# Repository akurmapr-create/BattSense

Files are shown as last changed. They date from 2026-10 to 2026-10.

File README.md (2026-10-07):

# BattSense

**ESP32 Li-ion battery monitor with voltage-based state-of-charge estimation, a custom KiCad PCB, OLED interface, and unit-tested firmware.**

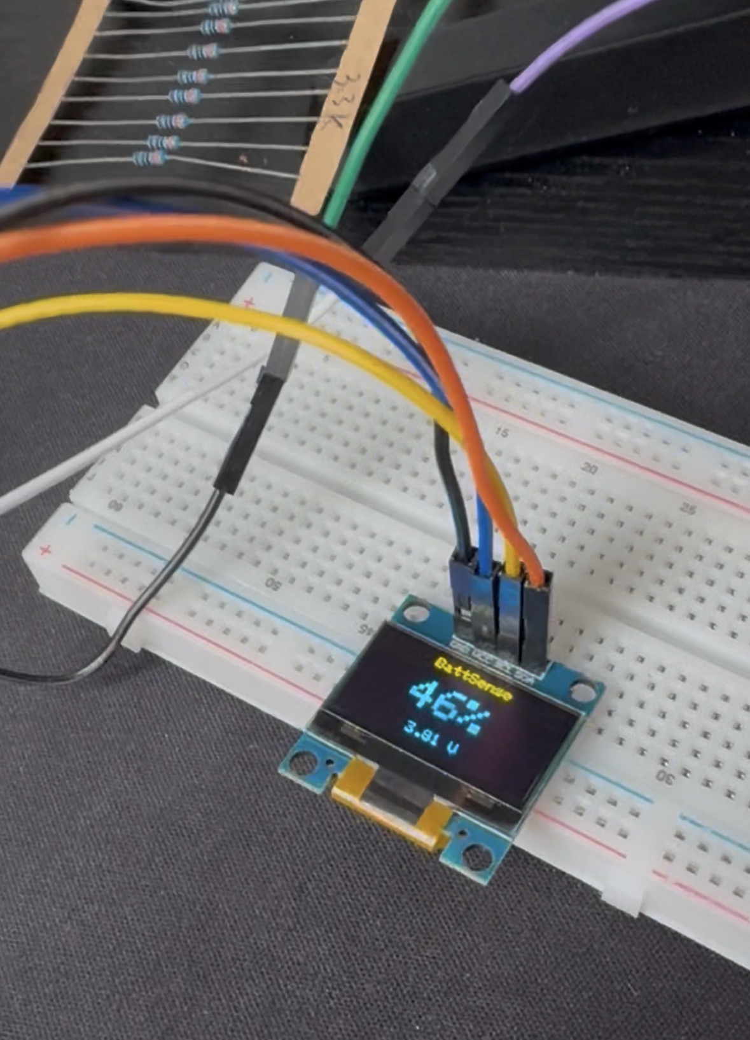
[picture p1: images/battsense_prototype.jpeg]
BattSense working prototype


BattSense is an embedded battery-monitoring system for a single-cell Li-ion battery. It measures battery voltage through a resistive analog front end, estimates battery state of charge (SoC), and displays the result locally on an OLED.

The project was developed from circuit design and breadboard validation through modular firmware, automated testing, PCB design, and enclosure development.

## Features

- Single-cell Li-ion battery voltage measurement
- ESP32 ADC acquisition on GPIO34
- Custom resistive analog front end
- ADC sample averaging
- Voltage-based state-of-charge estimation
- OCV-SoC lookup table with piecewise-linear interpolation
- 128×64 I2C OLED interface
- Modular C++ firmware
- Native unit testing with PlatformIO and Unity
- GitHub Actions continuous integration
- Custom 2-layer KiCad PCB
- Removable ESP32 DevKit architecture
- Through-hole design for hand assembly

## System Architecture

```text
          18650 Li-ion Cell
                  |
                  v
        Analog Voltage Divider
          20.1 kΩ / 13.3 kΩ
                  |
                  v
             GPIO34 ADC
                  |
                  v
           BatteryMonitor
                  |
           Battery Voltage
                  |
                  v
      StateOfChargeEstimator
                  |
           Estimated SoC
                  |
                  v
           DisplayManager
                  |
                  v
          128×64 I2C OLED
```

The firmware separates measurement, battery modeling, and presentation into independent modules.

## Hardware

### Analog Front End

The ESP32 measures the battery through a passive resistive divider.

Rev A uses:

```text
R_UPPER = 20.1 kΩ
R_LOWER = 13.3 kΩ
```

At a maximum single-cell Li-ion voltage of 4.2 V:

\[
V_{ADC}
=
4.2
\left(
\frac{13.3}
{20.1+13.3}
\right)
\approx
1.67V
\]

The divider presents a Thevenin resistance of approximately:

\[
R_{TH}
=
20.1k\Omega \parallel 13.3k\Omega
\approx
8.0k\Omega
\]

to the ESP32 ADC.

### Schematic

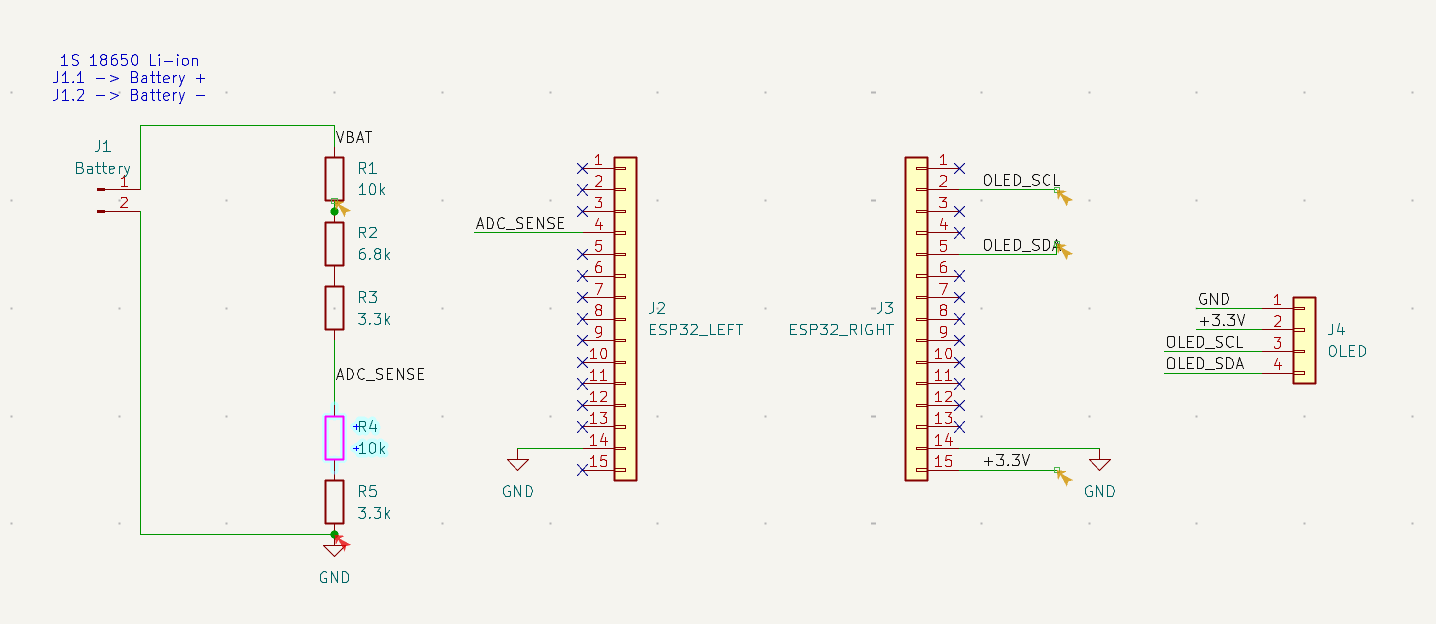
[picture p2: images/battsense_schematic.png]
BattSense schematic


The KiCad design includes:

- Battery input
- Voltage-divider analog front end
- Removable 30-pin ESP32 DevKit interface
- OLED I2C interface
- Power and ground connections

Additional analog-front-end documentation is available in [`docs/analog_front_end.md`](docs/analog_front_end.md).

## PCB Design

BattSense Rev A includes a custom **60 mm × 50 mm, 2-layer carrier PCB** designed in KiCad.

### PCB Layout

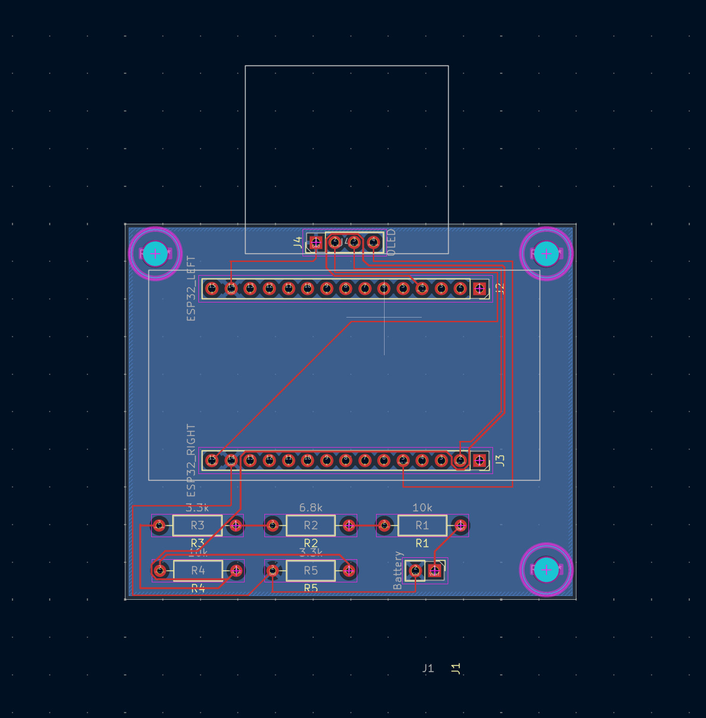
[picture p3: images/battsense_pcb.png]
BattSense PCB layout


### 3D Render

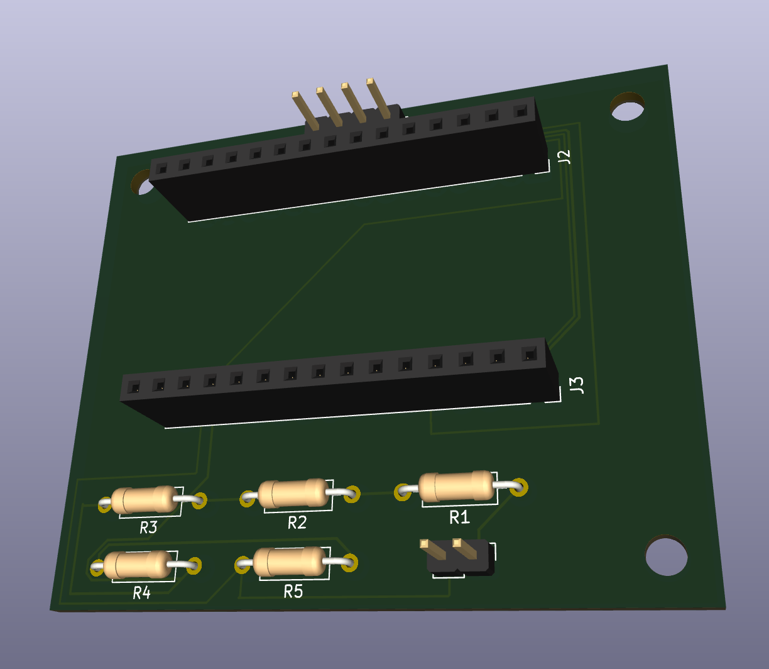
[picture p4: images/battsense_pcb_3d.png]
BattSense PCB 3D render


The PCB includes:

- Two 1×15 female sockets for a removable ESP32 DevKit
- Through-hole analog-front-end components
- OLED interface
- Battery interface
- B.Cu ground plane
- Three M3 enclosure mounting holes
- ESP32 orientation for left-side USB access

The completed layout passes KiCad design-rule checking with:

```text
Unrouted connections: 0
DRC violations:       0
```

Gerber and drill files have also been generated for Rev A fabrication.

## Firmware Architecture

The firmware is separated into dedicated modules:

```text
BatteryMonitor
      |
      | battery voltage
      v
StateOfChargeEstimator
      |
      | estimated SoC
      v
DisplayManager
      |
      v
OLED
```

### BatteryMonitor

Responsible for:

- ESP32 ADC configuration
- ADC acquisition
- Sample averaging
- ADC-voltage conversion
- Voltage-divider compensation
- Battery-voltage reporting

### StateOfChargeEstimator

Converts measured battery voltage into an estimated state of charge.

### DisplayManager

Presents battery voltage and estimated SoC on the OLED.

## State-of-Charge Estimation

BattSense Rev A uses a **voltage-based state-of-charge estimator**.

A Li-ion open-circuit-voltage versus state-of-charge lookup table is stored in firmware. When the measured voltage falls between two table entries, BattSense performs piecewise-linear interpolation.

For neighboring lookup points:

\[
(V_1,SOC_1)
\]

and

\[
(V_2,SOC_2)
\]

the interpolation factor is:

\[
t =
\frac{V-V_1}
{V_2-V_1}
\]

and the estimated state of charge is:

\[
SOC =
SOC_1 +
t(SOC_2-SOC_1)
\]

Values outside the lookup-table range are clamped to 0% or 100%.

The estimator is independent of ESP32 hardware, allowing it to be tested natively on a development machine.

> **Note:** Voltage-based SoC is an estimate rather than precision fuel gauging. Terminal voltage is affected by cell chemistry, temperature, aging, load current, and relaxation state.

See [`docs/state_of_charge.md`](docs/state_of_charge.md) for additional information about the model and its limitations.

## Testing

The SoC estimator is tested using Unity through PlatformIO's native environment.

Current tests cover:

- Lower-voltage clamping
- Upper-voltage clamping
- Exact lookup-table points
- 100% boundary behavior
- Piecewise-linear interpolation

Current result:

```text
5 test cases
5 succeeded
0 failed
```

Run the tests locally with:

```bash
cd firmware
pio test -e native
```

## Building the Firmware

BattSense uses PlatformIO with the Arduino ESP32 framework.

Clone the repository:

```bash
git clone https://github.com/akurmapr-create/BattSense.git
cd BattSense/firmware
```

Build the ESP32 firmware:

```bash
pio run -e esp32dev
```

Upload to a connected ESP32:

```bash
pio run -e esp32dev --target upload
```

Open the serial monitor:

```bash
pio device monitor
```

## Continuous Integration

BattSense uses GitHub Actions to automatically build and test the firmware on pushes and pull requests.



## Development Process

BattSense has been developed iteratively using physical hardware rather than only simulation.

```text
Requirements
    |
    v
Circuit Design
    |
    v
Breadboard Prototype
    |
    v
Measurement
    |
    v
Failure Identification
    |
    v
Design Revision
    |
    v
Validation
```

The analog front end, ADC acquisition, state-of-charge estimation, OLED interface, and PCB were developed and validated incrementally.

## Repository Structure

```text
BattSense/
|
├── .github/
│   └── workflows/
│       └── firmware.yml
|
├── docs/
│   ├── analog_front_end.md
│   ├── calculations.md
│   └── state_of_charge.md
|
├── firmware/
│   ├── include/
│   ├── src/
│   ├── test/
│   └── platformio.ini
|
├── hardware/
│   └── schematics/
│       └── BattSense_AFE/
|
├── images/
│   ├── battsense_prototype.jpeg
│   ├── battsense_schematic.png
│   ├── battsense_pcb.png
│   └── battsense_pcb_3d.png
|
└── README.md
```

## Rev A Status

- [x] Battery-voltage analog front end
- [x] Breadboard validation
- [x] ESP32 ADC integration
- [x] ADC averaging
- [x] State-of-charge estimator
- [x] SoC unit tests
- [x] OLED integration
- [x] GitHub Actions CI
- [x] KiCad schematic
- [x] Custom 2-layer PCB
- [x] ERC / DRC validation
- [x] Gerber generation
- [ ] Permanent perfboard assembly
- [ ] SolidWorks enclosure
- [ ] Final voltage validation with reference multimeter

## Roadmap

### Rev A

Complete the physical prototype:

- Assemble the permanent perfboard implementation
- Design and 3D-print the SolidWorks enclosure
- Mount the OLED and battery holder
- Complete final electrical validation

### Future Revisions

Potential improvements include:

- Cell-specific OCV-SoC characterization
- Current sensing
- Coulomb counting
- Temperature compensation
- Load-compensated SoC estimation
- Dedicated fuel-gauge evaluation
- Custom integrated ESP32 PCB

## Tools

- ESP32
- C++ / Arduino
- PlatformIO
- Unity
- GitHub Actions
- KiCad
- SolidWorks
- Git / GitHub

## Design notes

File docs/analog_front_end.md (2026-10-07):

# Analog Front-End Design

## Overview

The BattSense analog front-end measures the terminal voltage of a single-cell (1S) 18650 lithium-ion battery using the ESP32 ADC.

Because the maximum battery voltage exceeds the selected ADC measurement range, a passive resistive voltage divider scales the battery voltage before it reaches the ESP32.

> **Note**
>
> BattSense is a battery telemetry platform, **not** a Battery Management System (BMS). The analog front-end performs voltage measurement only. It does not provide charging control, cell balancing, over-current protection, or battery disconnect functionality.

---

## Requirements

| Requirement | Value |
| :--- | ---: |
| Battery chemistry | 1S Li-ion (18650) |
| Maximum battery voltage | 4.2 V |
| Microcontroller | ESP32-WROOM-32 DevKit |
| ADC peripheral | ADC1 |
| ADC input | GPIO34 |
| ADC resolution | 12 bit |
| ADC attenuation | 6 dB |
| Revised maximum ADC target | ~1.6 V |
| Target ADC source impedance | ~8 kΩ |

---

## System Architecture

```text
18650 Battery
      │
      ▼
Voltage Divider
      │
      ▼
ADC_SENSE
      │
      ▼
GPIO34 / ADC1
      │
      ▼
BatteryMonitor
      │
      ▼
Battery Voltage
      │
      ▼
Future Telemetry System
```

The ESP32 development board is powered independently through USB during Rev A testing. The 18650 cell is used as the measured source and does not power the ESP32.

The battery and ESP32 share a common ground so that the ADC measurement has the correct voltage reference.

---

## ADC Configuration

BattSense uses:

- ADC1
- GPIO34
- 12-bit ADC resolution
- 6 dB attenuation

ADC1 was selected to provide a dedicated analog measurement path and avoid the resource-sharing limitations associated with ADC2 when ESP32 wireless functionality is used.

The 6 dB attenuation setting was retained after prototype testing, but the analog front-end scaling was revised to keep the ADC input comfortably within the recommended measurement range.

---

# Analog Front-End Revision History

## Initial Design

The original analog front-end targeted:

\[
V_{BAT,MAX}=4.2V
\]

and:

\[
V_{ADC,MAX}=2.0V
\]

The resulting divider used nominal equivalent resistances of:

\[
R_{UPPER}=16.8k\Omega
\]

\[
R_{LOWER}=15.1k\Omega
\]

This produced a theoretical maximum ADC voltage of approximately:

\[
V_{ADC,MAX}\approx1.99V
\]

The design also maintained a source impedance of approximately 8 kΩ and a divider current of approximately 132 µA.

### Prototype Result

During breadboard testing, the ADC input was approximately 1.9 V and repeated calls to `analogRead()` returned:

```text
4095
4095
4095
...
```

A value of 4095 represents the maximum possible output of a 12-bit ADC and indicated that the ADC was saturating.

This demonstrated that the original 2.0 V target was too aggressive for reliable operation with the ESP32 ADC configured for 6 dB attenuation.

Rather than compensating for the behavior in firmware, the analog front-end was redesigned.

---

# Revised Analog Front-End

## Revised ADC Target

The maximum ADC target was reduced from approximately:

\[
2.0V
\]

to:

\[
\boxed{1.6V}
\]

at the maximum expected battery voltage of:

\[
4.2V
\]

This provides additional headroom below the upper portion of the usable ADC measurement range.

---

## Final Prototype Divider

The revised breadboard prototype uses equivalent resistances of:

\[
\boxed{R_{UPPER}=20.7k\Omega}
\]

and:

\[
\boxed{R_{LOWER}=13.0k\Omega}
\]

The divider topology is:

```text
VBAT
 │
 │
20.7 kΩ
 │
 ├──────── ADC_SENSE ─────── GPIO34
 │
13.0 kΩ
 │
GND
```

If an equivalent resistance is constructed from multiple physical resistors, the KiCad schematic documents the individual physical components used in the prototype.

---

## Revised Maximum ADC Voltage

The divider relationship is:

\[
V_{ADC}
=
V_{BAT}
\left(
\frac{R_{LOWER}}
{R_{UPPER}+R_{LOWER}}
\right)
\]

At the maximum battery voltage:

\[
V_{ADC}
=
4.2
\left(
\frac{13.0}
{20.7+13.0}
\right)
\]

Therefore:

\[
\boxed{V_{ADC,MAX}\approx1.62V}
\]

This is significantly lower than the original approximately 2.0 V target and prevents the ADC from operating near the saturation condition observed during initial testing.

---

## Source Impedance

The source impedance presented to the ADC is approximately the Thevenin equivalent resistance of the divider:

\[
R_{SOURCE}
=
R_{UPPER}\parallel R_{LOWER}
\]

For the revised divider:

\[
R_{SOURCE}
=
20.7k\Omega\parallel13.0k\Omega
\]

which gives:

\[
\boxed{R_{SOURCE}\approx7.99k\Omega}
\]

This remains extremely close to the original design target of approximately 8 kΩ.

---

## Divider Current

At the maximum battery voltage:

\[
R_{TOTAL}
=
20.7k\Omega+13.0k\Omega
=
33.7k\Omega
\]

The divider current is therefore:

\[
I_{DIVIDER}
=
\frac{4.2V}{33.7k\Omega}
\]

\[
\boxed{I_{DIVIDER}\approx125\mu A}
\]

The revised design therefore slightly reduces continuous divider current compared with the original prototype.

---

# Prototype Validation

## Initial Prototype

The initial divider produced an ADC input near approximately 1.9 V during testing.

The ESP32 repeatedly returned a raw ADC value of:

```text
4095
```

indicating ADC saturation.

---

## Revised Prototype

After changing the divider to approximately:

- 20.7 kΩ upper resistance
- 13.0 kΩ lower resistance

the raw ADC measurements were approximately:

```text
3109
3111
3103
3107
3113
3110
3114
3098
3093
3099
3145
3088
3098
3149
3119
3120
3107
3152
```

The ADC was therefore no longer saturated.

This experimentally verified that the revised analog-front-end scaling moved the ADC input back into a usable measurement region.

The variation between individual ADC samples will be characterized separately before deciding whether averaging or digital filtering is necessary.

---
## ADC Sample Averaging

After resolving the ADC saturation issue, repeated battery-voltage measurements were collected to characterize measurement variation.

With individual calibrated ADC measurements, the observed battery-voltage output ranged approximately from:

\[
3.808V \text{ to } 3.847V
\]

giving a peak-to-peak variation of:

\[
\Delta V_{PP}=39mV
\]

Because battery terminal voltage changes relatively slowly, multi-sample averaging was evaluated as a method of reducing random ADC variation.

BattSense was configured to average 16 calibrated ADC measurements for each reported voltage measurement.

After implementing 16-sample averaging, the observed battery-voltage range was approximately:

\[
3.818V \text{ to } 3.836V
\]

giving:

\[
\Delta V_{PP}=18mV
\]

The observed peak-to-peak variation was therefore reduced by approximately:

\[
\frac{39-18}{39}\times100\approx54\%
\]

Based on this experimental result, 16-sample averaging was retained in the Rev A BatteryMonitor implementation.

The raw ADC diagnostic remains a single conversion and therefore exhibits greater sample-to-sample variation than the averaged production voltage measurement.

# Firmware Interface

The analog front-end is represented in firmware by the `BatteryMonitor` module.

The module:

- Configures GPIO34 as the battery ADC input.
- Configures 12-bit ADC resolution.
- Configures 6 dB attenuation.
- Acquires raw ADC measurements for diagnostics.
- Obtains ADC-pin voltage measurements.
- Applies voltage-divider compensation.
- Returns the estimated battery terminal voltage.

The firmware uses the actual analog-front-end resistor values rather than a hard-coded divider multiplier.

Conceptually:

\[
V_{BAT}
=
V_{ADC}
\left(
\frac{R_{UPPER}+R_{LOWER}}
{R_{LOWER}}
\right)
\]

This keeps the firmware implementation directly traceable to the hardware design.

---

# Design Tradeoffs

| Decision | Benefit | Tradeoff |
| :--- | :--- | :--- |
| ADC1 / GPIO34 | Suitable dedicated analog input | Consumes one ADC1 channel |
| 6 dB attenuation | Retains selected ADC configuration | Requires external voltage scaling |
| ~1.6 V maximum target | Prevents observed saturation and adds headroom | Uses less of the theoretical ADC range |
| ~8 kΩ source impedance | Supports reliable ADC sampling | Requires relatively low divider resistance |
| Passive divider | Simple and inexpensive | Continuously draws battery current |
| ~125 µA divider current | Acceptable for Rev A | Too high for future ultra-low-power designs |

---

# Future Improvements

Potential future improvements include:

- Characterizing ADC measurement error across multiple battery voltages.
- Quantifying sample-to-sample ADC noise.
- Determining whether sample averaging improves measurement repeatability.
- Characterizing divider tolerance using higher-accuracy test equipment.
- Adding a switched divider for lower sleep current.
- Evaluating an ADC input capacitor if higher divider resistance is used.
- Designing a dedicated BattSense PCB after breadboard validation is complete.

Filtering and averaging will only be introduced after measurement data demonstrates a need for them.

---

# Lessons Learned

The Rev A voltage-measurement subsystem demonstrated the importance of validating analog designs against real hardware rather than relying exclusively on theoretical calculations.

Key findings included:

1. The original approximately 2.0 V ADC target caused the 12-bit ESP32 ADC reading to saturate at 4095 when using 6 dB attenuation.

2. The analog front end was redesigned for approximately 1.6 V maximum ADC input at a 4.2 V battery voltage.

3. The revised 20.7 kΩ / 13.0 kΩ divider eliminated the observed ADC saturation while maintaining approximately 8 kΩ source impedance.

4. Separating raw ADC count, ADC-pin voltage, and reconstructed battery voltage significantly simplified troubleshooting.

5. Measurements were used to justify signal-processing changes rather than adding filtering preemptively.

6. Sixteen-sample averaging reduced observed battery-voltage peak-to-peak variation from approximately 39 mV to 18 mV.

7. The available multimeter was sufficient for functional validation but was not accurate enough to characterize absolute measurement accuracy. Therefore, BattSense Rev A claims functional and repeatable battery telemetry rather than precision voltage measurement.

# References

- ESP32-WROOM-32 Datasheet
- ESP32 Technical Reference Manual
- ESP-IDF ADC Documentation
- Arduino-ESP32 ADC API Documentation

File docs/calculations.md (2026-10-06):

# Analog Front-End Calculations

This document contains the calculations used to design and revise the BattSense battery-voltage analog front end.

The original design calculations are retained to document the engineering process that led to the revised prototype.

---

# 1. System Requirements

Maximum battery voltage:

\[
V_{BAT,MAX}=4.2V
\]

ADC:

```text
ESP32 ADC1
GPIO34
12-bit resolution
6 dB attenuation
```

Target ADC source impedance:

\[
R_{SOURCE}\approx8k\Omega
\]

---

# 2. Original Analog Front-End

## Original ADC Target

The initial design targeted:

\[
V_{ADC,MAX}=2.0V
\]

at:

\[
V_{BAT,MAX}=4.2V
\]

---

## Original Divider Ratio

The voltage-divider equation is:

\[
V_{OUT}
=
V_{IN}
\left(
\frac{R_{LOWER}}
{R_{UPPER}+R_{LOWER}}
\right)
\]

Substituting the original requirements:

\[
2.0
=
4.2
\left(
\frac{R_{LOWER}}
{R_{UPPER}+R_{LOWER}}
\right)
\]

Therefore:

\[
\frac{R_{LOWER}}
{R_{UPPER}+R_{LOWER}}
=
\frac{2.0}{4.2}
\]

\[
=
\frac{10}{21}
\]

Solving:

\[
10(R_{UPPER}+R_{LOWER})
=
21R_{LOWER}
\]

\[
10R_{UPPER}+10R_{LOWER}
=
21R_{LOWER}
\]

\[
10R_{UPPER}
=
11R_{LOWER}
\]

Therefore:

\[
\boxed{
R_{UPPER}:R_{LOWER}=11:10
}
\]

---

## Original Prototype Values

The initial prototype used nominal equivalent resistances of:

\[
R_{UPPER}=16.8k\Omega
\]

\[
R_{LOWER}=15.1k\Omega
\]

The actual physical prototype used series combinations to approximate these equivalent resistances.

---

## Original Maximum ADC Voltage

\[
V_{ADC}
=
4.2
\left(
\frac{15.1}
{16.8+15.1}
\right)
\]

\[
V_{ADC}
=
4.2
\left(
\frac{15.1}
{31.9}
\right)
\]

\[
\boxed{
V_{ADC}\approx1.99V
}
\]

---

## Original Source Impedance

\[
R_{SOURCE}
=
R_{UPPER}\parallel R_{LOWER}
\]

\[
R_{SOURCE}
=
\frac{(16.8k)(15.1k)}
{16.8k+15.1k}
\]

\[
\boxed{
R_{SOURCE}\approx7.95k\Omega
}
\]

---

## Original Divider Current

\[
R_{TOTAL}
=
16.8k+15.1k
=
31.9k\Omega
\]

\[
I
=
\frac{4.2V}{31.9k\Omega}
\]

\[
\boxed{
I\approx132\mu A
}
\]

---

# 3. Initial Prototype Test Result

During breadboard validation, the ADC input approached approximately 1.9 V.

Repeated raw ADC measurements returned:

```text
4095
4095
4095
...
```

For a 12-bit ADC:

\[
ADC_{MAX}=2^{12}-1=4095
\]

The repeated maximum value indicated ADC saturation.

The analog-front-end design was therefore revised instead of attempting to compensate for the saturation in firmware.

---

# 4. Revised Analog Front-End

## Revised ADC Target

The new design target is:

\[
\boxed{
V_{ADC,MAX}\approx1.6V
}
\]

for:

\[
V_{BAT,MAX}=4.2V
\]

The required divider ratio is therefore approximately:

\[
K
=
\frac{1.6}{4.2}
\]

\[
\boxed{
K\approx0.381
}
\]

where:

\[
K=
\frac{R_{LOWER}}
{R_{UPPER}+R_{LOWER}}
\]

---

# 5. Revised Prototype Resistor Selection

Available resistor combinations produced:

\[
\boxed{
R_{UPPER}=20.7k\Omega
}
\]

\[
\boxed{
R_{LOWER}=13.0k\Omega
}
\]

Total divider resistance:

\[
R_{TOTAL}
=
20.7k+13.0k
\]

\[
\boxed{
R_{TOTAL}=33.7k\Omega
}
\]

---

# 6. Revised Divider Ratio

\[
K
=
\frac{13.0}
{20.7+13.0}
\]

\[
K
=
\frac{13.0}{33.7}
\]

\[
\boxed{
K\approx0.3858
}
\]

---

# 7. Revised Maximum ADC Voltage

At the maximum battery voltage:

\[
V_{ADC,MAX}
=
4.2(0.3858)
\]

\[
\boxed{
V_{ADC,MAX}\approx1.62V
}
\]

This is close to the revised 1.6 V design target.

---

# 8. Revised Source Impedance

The ADC sees approximately the Thevenin equivalent resistance of the divider:

\[
R_{SOURCE}
=
R_{UPPER}\parallel R_{LOWER}
\]

\[
R_{SOURCE}
=
\frac{(20.7k)(13.0k)}
{20.7k+13.0k}
\]

\[
R_{SOURCE}
=
\frac{269.1}
{33.7}
k\Omega
\]

\[
\boxed{
R_{SOURCE}\approx7.99k\Omega
}
\]

This is almost exactly the original 8 kΩ source-impedance target.

---

# 9. Revised Divider Current

At maximum battery voltage:

\[
I_{DIVIDER}
=
\frac{V_{BAT}}
{R_{TOTAL}}
\]

\[
I_{DIVIDER}
=
\frac{4.2}
{33.7k}
\]

\[
\boxed{
I_{DIVIDER}\approx125\mu A
}
\]

The revised divider therefore consumes slightly less current than the original design.

---

# 10. Battery Voltage Reconstruction

The ADC measures:

\[
V_{ADC}
=
V_{BAT}
\left(
\frac{R_{LOWER}}
{R_{UPPER}+R_{LOWER}}
\right)
\]

Solving for battery voltage:

\[
V_{BAT}
=
V_{ADC}
\left(
\frac{R_{UPPER}+R_{LOWER}}
{R_{LOWER}}
\right)
\]

Using the revised resistor values:

\[
V_{BAT}
=
V_{ADC}
\left(
\frac{20.7+13.0}
{13.0}
\right)
\]

\[
V_{BAT}
=
V_{ADC}
\left(
\frac{33.7}{13.0}
\right)
\]

Therefore:

\[
\boxed{
V_{BAT}\approx2.5923V_{ADC}
}
\]

The firmware calculates this relationship from the resistor values rather than storing `2.5923` as a hard-coded multiplier.

---

# 11. Revised Prototype ADC Test

After installing the revised divider, the following raw ADC samples were observed:

```text
3109
3111
3103
3107
3113
3110
3114
3098
3093
3099
3145
3088
3098
3149
3119
3120
3107
3152
```

Unlike the original design, the ADC was no longer pinned at:

```text
4095
```

This verifies that the revised voltage divider successfully moved the ADC input away from saturation.

The sample variation will be characterized separately before deciding whether digital averaging or filtering is necessary.

---

# 12. Design Comparison

| Parameter | Original Design | Revised Design |
| :--- | ---: | ---: |
| Maximum battery voltage | 4.2 V | 4.2 V |
| ADC target | 2.0 V | ~1.6 V |
| Upper resistance | 16.8 kΩ | 20.7 kΩ |
| Lower resistance | 15.1 kΩ | 13.0 kΩ |
| Maximum ADC voltage | ~1.99 V | ~1.62 V |
| Source impedance | ~7.95 kΩ | ~7.99 kΩ |
| Divider current @ 4.2 V | ~132 µA | ~125 µA |
| Raw ADC prototype behavior | Saturated at 4095 | ~3100 counts |

---

# 13. Engineering Conclusion

The original analog front-end met its calculated divider and source-impedance requirements but produced ADC saturation during physical testing.

The revised design:

- Reduces maximum ADC input voltage.
- Preserves approximately 8 kΩ source impedance.
- Slightly reduces continuous divider current.
- Eliminates the observed raw ADC saturation.
- Maintains sufficient range for measurement of a 1S lithium-ion battery.

This revision demonstrates the complete engineering cycle:

```text
Requirements
    ↓
Design
    ↓
Calculation
    ↓
Prototype
    ↓
Test
    ↓
Failure Observation
    ↓
Root-Cause Investigation
    ↓
Design Revision
    ↓
Verification
```

Further optimization will be based on measured ADC accuracy and noise rather than assumptions.

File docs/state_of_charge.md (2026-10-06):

# State-of-Charge Estimation

## Overview

BattSense Rev A estimates the state of charge (SoC) of a single-cell lithium-ion battery using the battery voltage measured by the `BatteryMonitor` module.

The estimator uses a tabular open-circuit-voltage (OCV) versus state-of-charge relationship and piecewise-linear interpolation between adjacent lookup-table points.

The resulting percentage is an **estimated state of charge** and should not be interpreted as a precision measurement of remaining battery capacity.

---

## System Architecture

The state-of-charge estimator is intentionally separated from the battery measurement hardware and firmware.

```text
18650 Battery
      |
      v
Analog Front End
      |
      v
BatteryMonitor
      |
      | Battery Voltage
      v
StateOfChargeEstimator
      |
      | Estimated SoC (%)
      v
DisplayManager
      |
      v
OLED Display
```

Each module has a separate responsibility:

- `BatteryMonitor` measures battery voltage.
- `StateOfChargeEstimator` converts battery voltage into an estimated SoC.
- `DisplayManager` will present the resulting information to the user.

This separation allows the battery measurement, SoC model, and user interface to evolve independently.

---

# Rev A Estimation Method

BattSense Rev A uses:

> **OCV-SoC lookup table + piecewise-linear interpolation**

A lookup-table approach was selected because the lithium-ion voltage-versus-state-of-charge relationship is nonlinear.

A simple linear relationship such as:

\[
3.0V = 0\%
\]

and:

\[
4.2V = 100\%
\]

would incorrectly assume that battery voltage changes linearly with state of charge.

Instead, BattSense stores several OCV-SoC operating points and interpolates between neighboring points.

---

# OCV-SoC Lookup Table

BattSense Rev A uses the following generic lithium-ion OCV-SoC reference model:

| OCV (V) | SoC (%) |
| ---: | ---: |
| 3.0519 | 0 |
| 3.6594 | 10 |
| 3.7167 | 20 |
| 3.7611 | 30 |
| 3.7915 | 40 |
| 3.8275 | 50 |
| 3.8772 | 60 |
| 3.9401 | 70 |
| 4.0128 | 80 |
| 4.0923 | 90 |
| 4.1797 | 100 |

The lookup-table values are based on the example tabular OCV-SoC model presented in the following review:

> M. A. Hannan et al.,  
> "Open-Circuit Voltage Models for Battery Management Systems: A Review,"  
> *Energies*, vol. 15, no. 18, 6803, 2022.

DOI:

https://doi.org/10.3390/en15186803

The referenced work discusses tabular OCV-SoC representations and interpolation-based battery models.

BattSense uses this data as a **generic Rev A approximation** rather than as a cell-specific characterization of the particular 18650 used during development.

---

# Piecewise-Linear Interpolation

When the measured battery voltage falls between two entries in the lookup table, BattSense estimates the state of charge using linear interpolation between those neighboring points.

Consider two adjacent lookup-table points:

\[
(V_1,SOC_1)
\]

and:

\[
(V_2,SOC_2)
\]

For a measured battery voltage:

\[
V
\]

where:

\[
V_1 < V < V_2
\]

the interpolation fraction is:

\[
t =
\frac{V-V_1}
{V_2-V_1}
\]

The estimated state of charge is then:

\[
SOC =
SOC_1 +
t(SOC_2-SOC_1)
\]

---

## Example

Suppose the battery voltage is:

\[
V=3.85V
\]

The surrounding lookup-table entries are:

\[
3.8275V \rightarrow 50\%
\]

and:

\[
3.8772V \rightarrow 60\%
\]

The interpolation fraction is:

\[
t=
\frac{3.85-3.8275}
{3.8772-3.8275}
\]

\[
t\approx0.453
\]

The estimated state of charge is therefore:

\[
SOC=
50+0.453(60-50)
\]

\[
SOC\approx54.5\%
\]

Therefore:

\[
\boxed{SOC\approx55\%}
\]

The OLED display may round the calculated value to the nearest whole percentage.

---

# Boundary Conditions

The estimator must always return a value between:

\[
0\%
\]

and:

\[
100\%
\]

If the measured voltage is greater than or equal to the highest lookup-table voltage:

\[
V\ge4.1797V
\]

the estimator returns:

\[
\boxed{SOC=100\%}
\]

If the measured voltage is less than or equal to the lowest lookup-table voltage:

\[
V\le3.0519V
\]

the estimator returns:

\[
\boxed{SOC=0\%}
\]

This prevents invalid outputs such as:

```text
107%
```

or:

```text
-8%
```

---

# Firmware Architecture

The estimator is implemented as a dedicated firmware module:

```text
firmware/
├── include/
│   └── StateOfChargeEstimator.h
│
└── src/
    └── StateOfChargeEstimator.cpp
```

The public interface is intentionally small.

Conceptually:

```cpp
class StateOfChargeEstimator
{
public:
    float estimate(float batteryVoltage) const;
};
```

The module receives battery voltage as its input and returns estimated state of charge.

For example:

```text
Input:
3.85 V

Output:
~54.5 %
```

---

# Separation of Model and Algorithm

The OCV-SoC lookup table represents the **battery model**.

The interpolation function represents the **estimation algorithm**.

These are intentionally separated.

```text
OCV-SOC Lookup Table
        |
        | battery model
        v
Interpolation Algorithm
        |
        v
Estimated SoC
```

This means a future BattSense revision could replace the generic lookup table with cell-specific characterization data without redesigning the interpolation algorithm.

---

# Why SoC Estimation Is Not Part of BatteryMonitor

`BatteryMonitor` is responsible for answering:

> What is the measured battery voltage?

`StateOfChargeEstimator` is responsible for answering:

> Given this voltage and our battery model, what is the estimated state of charge?

These are separate responsibilities.

Keeping them separate prevents battery-model assumptions from becoming coupled to the ADC measurement implementation.

---

# Limitations

Voltage-based state-of-charge estimation has important limitations.

## Terminal Voltage Is Not Always OCV

Open-circuit voltage is ideally measured when the battery has been allowed to rest and transient electrochemical effects have decayed.

BattSense Rev A measures battery terminal voltage.

Under load:

\[
V_{terminal}
\neq
V_{OCV}
\]

because battery internal resistance and electrochemical polarization can cause the terminal voltage to change.

Therefore, the calculated percentage should be interpreted as an approximation.

---

## Cell Chemistry

Different lithium-ion chemistries have different OCV-SoC relationships.

Examples include:

- NMC
- NCA
- LCO
- LFP

BattSense Rev A does not attempt to automatically identify battery chemistry.

The selected model is intended as a generic lithium-ion approximation for the Rev A prototype.

---

## Temperature

Battery voltage behavior changes with temperature.

BattSense Rev A does not perform temperature compensation.

Temperature-aware SoC estimation may be investigated in a future revision.

---

## Aging

As lithium-ion cells age:

- Internal resistance increases.
- Available capacity decreases.
- Voltage behavior may change.

The Rev A estimator does not compensate for battery aging.

---

## Load Current

BattSense Rev A does not measure battery current.

Therefore it cannot compensate for load-induced voltage drop or perform coulomb counting.

This limits the accuracy of voltage-only state-of-charge estimation.

---

# Why BattSense Uses Voltage-Based SoC in Rev A

The goal of Rev A is not to implement a precision fuel gauge.

The goal is to build a modular embedded telemetry platform while demonstrating:

- Analog battery-voltage measurement
- ADC configuration and calibration
- Hardware/firmware co-design
- Lookup-table modeling
- Piecewise-linear interpolation
- Modular C++ architecture
- Automated testing
- CI-based firmware development
- Embedded user-interface development

Voltage-based SoC estimation provides an appropriate balance between useful functionality and Rev A project scope.

---

# Future Improvements

Possible future improvements include:

- Cell-specific OCV-SoC characterization
- Temperature compensation
- Battery current measurement
- Coulomb counting
- Load compensation
- Battery aging compensation
- Rest-state detection
- Combining OCV estimation with coulomb counting
- Dedicated fuel-gauge IC evaluation

These improvements are intentionally outside the scope of BattSense Rev A.

---

# References

## Primary OCV Model Reference

M. A. Hannan et al.,  
"Open-Circuit Voltage Models for Battery Management Systems: A Review,"  
*Energies*, vol. 15, no. 18, 6803, 2022.

DOI:

https://doi.org/10.3390/en15186803

---

## Additional Reference

H. He, X. Zhang, R. Xiong, Y. Xu, and H. Guo,  
"Online model-based estimation of state-of-charge and open-circuit voltage of lithium-ion batteries in electric vehicles,"  
*Energy*, vol. 39, no. 1, pp. 310-318, 2012.

DOI:

https://doi.org/10.1016/j.energy.2012.01.009

This work discusses experimentally derived OCV-SoC relationships and interpolation-based SoC estimation.

---

# Rev A Definition

BattSense reports:

> **Estimated Battery State of Charge**

It does **not** claim to provide precision remaining-capacity measurement or commercial fuel-gauge accuracy.

This distinction should be maintained in firmware documentation, the OLED user interface, and the project README.

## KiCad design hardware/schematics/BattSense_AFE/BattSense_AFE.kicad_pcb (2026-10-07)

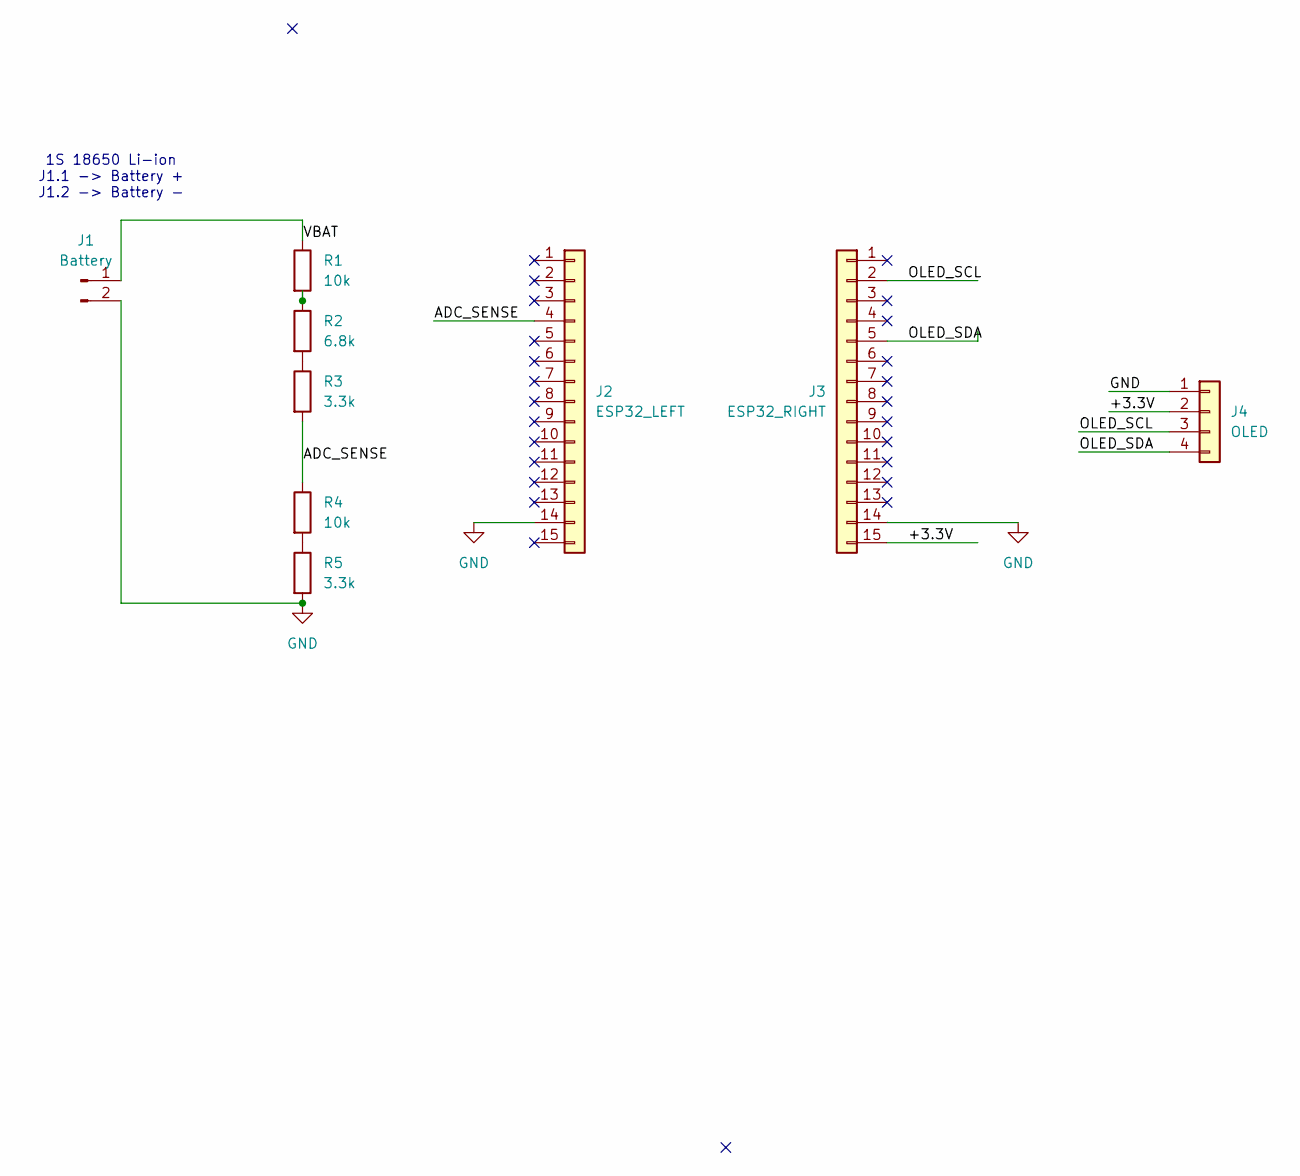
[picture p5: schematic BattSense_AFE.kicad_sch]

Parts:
J1: Battery; PinHeader_1x02_P2.54mm_Vertical
J2: ESP32_LEFT; PinSocket_1x15_P2.54mm_Vertical
J3: ESP32_RIGHT; PinSocket_1x15_P2.54mm_Vertical
J4: OLED; PinHeader_1x04_P2.54mm_Vertical
R1, R4: 10k; R_Axial_DIN0207_L6.3mm_D2.5mm_P10.16mm_Horizontal
R2: 6.8k; R_Axial_DIN0207_L6.3mm_D2.5mm_P10.16mm_Horizontal
R3, R5: 3.3k; R_Axial_DIN0207_L6.3mm_D2.5mm_P10.16mm_Horizontal

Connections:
/+3.3V: J3.15, J4.2
/ADC_SENSE: J2.4, R3.2, R4.1
/OLED_SCL: J3.2, J4.3
/OLED_SDA: J3.5, J4.4
/VBAT: J1.1, R1.1
GND: J1.2, J2.14, J3.14, J4.1, R5.2
unnamed: R1.2, R2.1
unnamed: R2.2, R3.1
unnamed: R4.2, R5.1

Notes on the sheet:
1S 18650 Li-ion J1.1 -> Battery + J1.2 -> Battery -

Board: 2 copper layers, 9 parts (0 on the bottom side), 9 nets, no tracks yet.

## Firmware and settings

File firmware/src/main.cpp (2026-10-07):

#include <Arduino.h>

#include "BatteryMonitor.h"
#include "StateOfChargeEstimator.h"
#include "DisplayManager.h"

BatteryMonitor battery;
StateOfChargeEstimator socEstimator;
DisplayManager display;

void setup()
{
    Serial.begin(115200);

    battery.begin();

    if (!display.begin())
    {
        Serial.println("OLED initialization failed.");

        while (true)
        {
            delay(1000);
        }
    }

    Serial.println("BattSense initialized.");
}

void loop()
{
    const BatteryDiagnostics diagnostics = battery.getDiagnostics();

    const float stateOfCharge =
        socEstimator.estimate(diagnostics.batteryVoltage);

    display.showBattery(
        diagnostics.batteryVoltage,
        stateOfCharge
    );

    Serial.println("----- Battery Diagnostics -----");

    Serial.print("Raw ADC:          ");
    Serial.println(diagnostics.rawAdcCount);

    Serial.print("ADC Voltage:      ");
    Serial.print(diagnostics.adcVoltage, 3);
    Serial.println(" V");

    Serial.print("Battery Voltage:  ");
    Serial.print(diagnostics.batteryVoltage, 3);
    Serial.println(" V");

    Serial.print("Estimated SoC:    ");
    Serial.print(stateOfCharge, 1);
    Serial.println(" %");

    Serial.println("-------------------------------");

    delay(1000);
}

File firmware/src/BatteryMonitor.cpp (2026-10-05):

#include "BatteryMonitor.h"

void BatteryMonitor::begin()
{
    analogReadResolution(ADC_RESOLUTION);
    analogSetPinAttenuation(ADC_PIN, ADC_6db);
}

float BatteryMonitor::getVoltage()
{
    const float adcVoltage = readADCVoltage();

    return adcToBatteryVoltage(adcVoltage);
}

BatteryDiagnostics BatteryMonitor::getDiagnostics()
{
    BatteryDiagnostics diagnostics{};

    diagnostics.rawAdcCount = readRawADC();
    diagnostics.adcVoltage = readADCVoltage();
    diagnostics.batteryVoltage =
        adcToBatteryVoltage(diagnostics.adcVoltage);

    return diagnostics;
}

int BatteryMonitor::readRawADC()
{
    return analogRead(ADC_PIN);
}

float BatteryMonitor::readADCVoltage()
{
    const uint32_t millivolts = analogReadMilliVolts(ADC_PIN);

    return millivolts / 1000.0f;
}

float BatteryMonitor::adcToBatteryVoltage(float adcVoltage)
{
    return adcVoltage *
           ((R_UPPER_OHMS + R_LOWER_OHMS) / R_LOWER_OHMS);
}

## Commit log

2026-10-05 Add BatteryMonitor module skeleton
2026-10-05 Implement battery voltage measurement pipeline
2026-10-05 Add Rev A analog front-end schematic
    [BattSense_AFE.kicad_sch]
2026-10-06 Add state of charge estimator and unit tests
2026-10-06 Integrate battery voltage and state of charge estimation
2026-10-06 Integrate battery SoC estimation and OLED display
2026-10-07 Complete BattSense Rev A hardware and documentation
    [BattSense_AFE-B_Cu.gbr, BattSense_AFE-B_Mask.gbr, BattSense_AFE-B_Silkscreen.gbr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]
